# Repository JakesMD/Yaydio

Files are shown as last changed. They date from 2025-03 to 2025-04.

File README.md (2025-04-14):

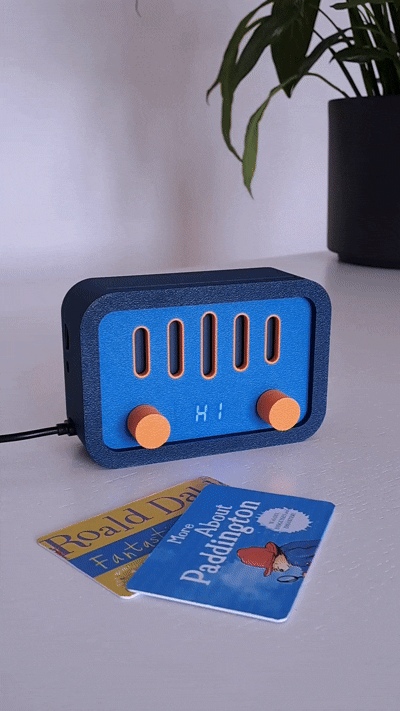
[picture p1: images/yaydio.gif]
Yaydio!


# Yaydio! 📻
**No more scratched CDs!**

**Yaydio!** is a portable music player designed for kids, ditching the hassle of CDs in favor of easy-to-use keycards.

## ✨ Features
- **Keycard playback:** Insert a keycard to instantly play an album.
- **Simple controls:** Play/pause, next/previous track, volume up/down.
- **Audio options:** Built-in speaker or connect headphones via the 3.5mm jack.
- **High capacity:**
    - Up to 999 songs per album
    - Up to 9999 albums
    - Up to 65535 songs in total
    - Supports micro SD cards up to 32GB.
- **MP3 compatibility:** Plays all your favorite MP3 files.
- **Affordable & accessible:** Works with cost-effective MF S50 RFID keycards.

## 🕹️ Usage

### Play / pause
Inserting a keycard into the **Yaydio!** will automatically start the playback.

Press either knob to pause or resume the playback.

Remove the keycard to stop the playback.

### Volume control
Turn the left knob to increase or decrease the volume.

### Next / previous track
Turn the right knob to skip to the next or previous track.

### Setup
1. Format the SD card to FAT16 or FAT32 and name it `YAYDIO`.
2. Copy the `README.txt` file onto the SD card.
3. Windows only: Download [DriveSort](https://www.anerty.net/software/file/DriveSort/?lang=en) and copy `DriveSort.exe` onto the SD card.
4. macOS only: Download [FatDriveSorter](https://fat-drive-sorter.netlify.app) and copy `FatDriveSorter.app` onto the SD card.

### Add albums to the SD card
1.  Create a new folder named `0001`, where "1" represents the next album number.
2.  Copy the album's songs into the folder you created.
3.  Rename the first song of the album to `001.mp3`.
4.  Repeat steps 1-3 for each album.
5.  Windows only: Use `DriveSort` to sort the files alphabetically in the SD card's table.
    -   Sort by `long name` and `ascending`.
    -   Remember to press the save button.
    -   You may need to sort every new folder individually and press save after each one.
6.  macOS only: Use `FatDriveSorter` to sort the files alphabetically in the SD card's table.
    -   Next to `Order:` select `Directories first`.
    -   Tick the box next to `Case-sensitive:`.

### Assign an album to a keycard

1. Insert the keycard into the **Yaydio!**.
2. Press the left and right knobs simultaneously.
3. Turn the right knob to select the album number.
4. Press the right knob to write the album number to the keycard.

## 🔨 Make your own

### 🧱 Parts
For a list of parts see [this issue](https://github.com/JakesMD/Yaydio/issues/1).

### 🧵 Wiring

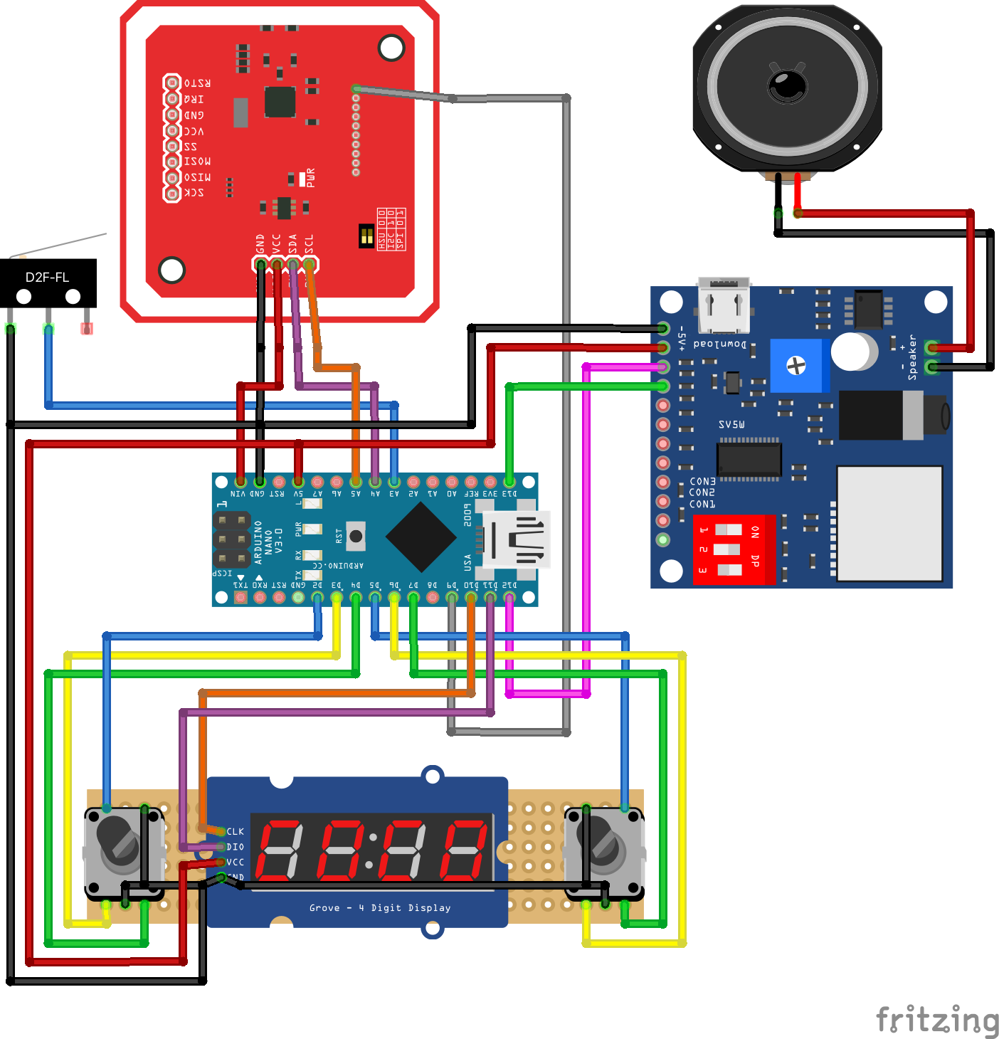
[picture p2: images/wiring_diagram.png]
Wiring Diagram


| Left Rotary Encoder | Arduino Nano |
| --- | --- |
| SW | D2 |
| SW GND | GND |
| DT | D3 |
| CLK | D4 |
| GND | GND |

| Right Rotary Encoder | Arduino Nano |
| --- | --- |
| SW | D5 |
| SW GND | GND |
| DT | D6 |
| CLK | D7 |
| GND | GND |

| 4-Digit 7-Segment 0.36 Inch TM1637 | Arduino Nano |
| --- | --- |
| CLK | D10 |
| DIO | D11 |
| GND | GND |
| 5V | 5V |

| Card Switch | Arduino Nano |
| --- | --- |
| NO | A3 |
| COM | GND |

| PN532 NFC Module V3 | Arduino Nano |
| --- | --- |
| GND | GND |
| VCC | VIN (NOT 5V) |
| SDA | A4 |
| SCL | A5 |
| RSTPDN | D9 |
| Switches: ON, OFF (I2C mode) |

Note: In the images below you'll see that I also connected the IRQ pin to the Arduino. This is not required.

| DY-SV5W Voice Module  | Arduino Nano |
| --- | --- |
| - | GND |
| + | 5V |
| TXD | D12 |
| RXD | D13 |
| Switches: OFF, OFF, ON (UART mode) |

| DY-SV5W Voice Module  | Speaker |
| --- | --- |
| Speaker + | + |
| Speaker - | - |

### 🏗️ Assembly

[yaydio.step](yaydio.step) contains the models of the 3D-printed parts.

**Printer:** Bambu Lab A1 with AMS

**Nozzle:** 0.4mm

**Preset:** `0.20mm Standard @BBL A1` with supports enabled

**Filaments:**
- Bambu Lab PLA Matte Mandarin Orange (11300)
- Bambu Lab PLA Matte Marine Blue (11600)
- Bambu Lab PLA Matte Dark Blue (11602)

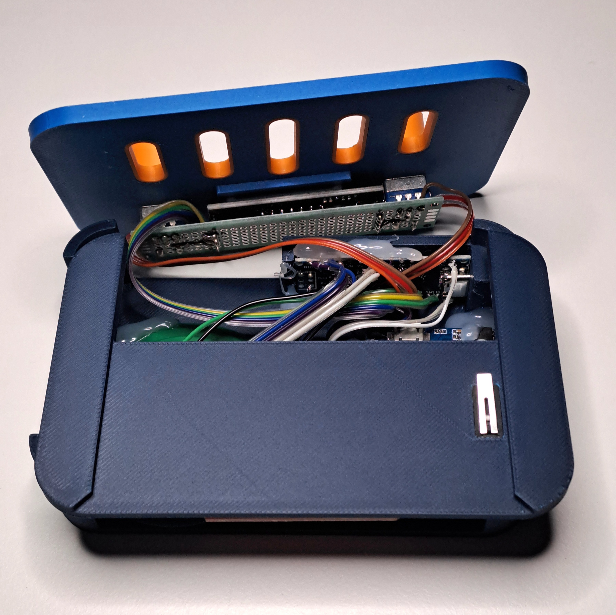
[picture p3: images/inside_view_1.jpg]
Inside view 1

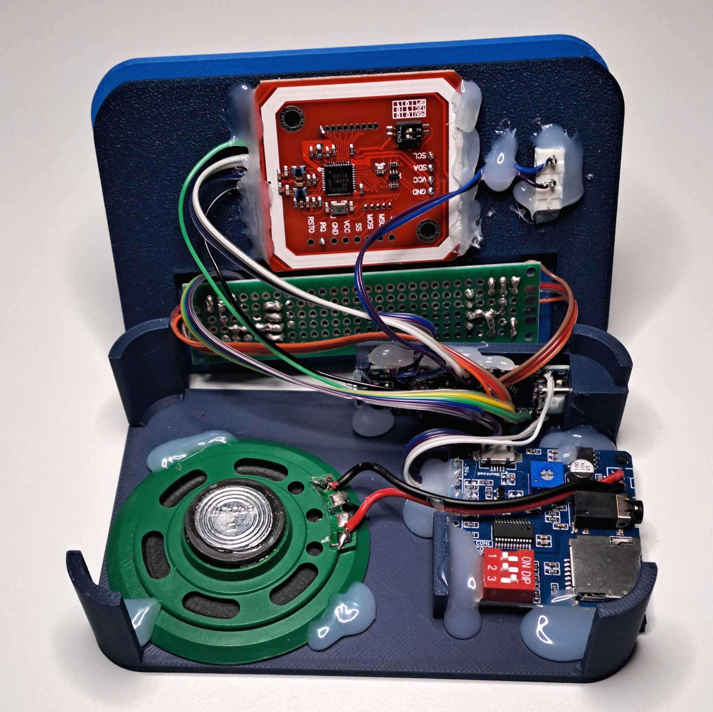
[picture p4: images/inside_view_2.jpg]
Inside view 2


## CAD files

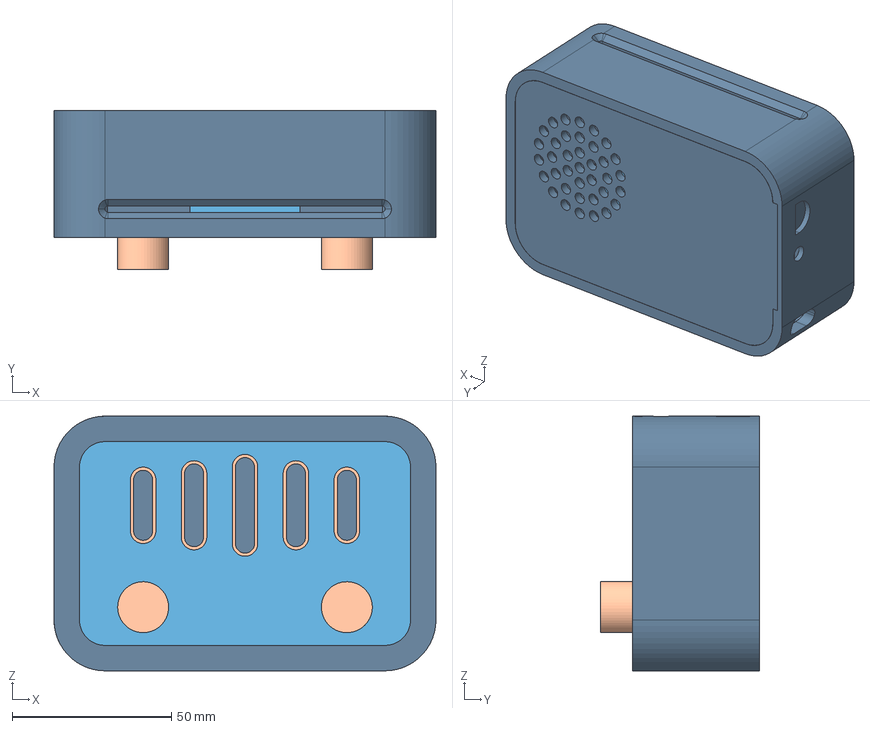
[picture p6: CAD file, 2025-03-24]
yaydio.step
120.0 x 50.0 x 80.0 mm
Front Plate
Knob x 2
Back Plate
NFC Plate

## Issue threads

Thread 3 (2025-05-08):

Suggestion: Allow reading NFC cards across Yaydio devices even if UID differs

iliesaya, 2025-05-08:
Hi,

  I built two Yaydio devices and ran into an interoperability issue when using NFC cards across devices.

  ### 🔧 What happens:

  If I write an NFC card with one Yaydio device (e.g., writing block 4 with an album number and a custom UID), the second Yaydio device **fails to read** it, even though the block structure and keys are valid. The NFC read operation returns `FAIL`.

  After debugging, I realized this happens because the card’s UID is different from what the reading Yaydio device expects or assumes internally.

  ### 🧪 Repro case:

  - Device A writes album 0002 to a card with UID: `1E 0C 58 3E`
  - Device B writes album 0002 to a card with UID: `36 69 63 3E`
  - Each device can read its own card correctly
  - The other device fails to read the card written by the other one

  This means that Yaydio currently **ties the album reading logic to the UID**, which is problematic when using UID-writable “magic” MIFARE Classic cards or cloning workflows (e.g., with Flipper Zero).

  ### 💡 Suggestion:

  Please consider modifying the NFC handling logic in Yaydio so that reading a card is based only on successful authentication (key match) and block 4 content — and **not dependent on UID value**.

  That way, the same NFC card can be used across all Yaydio devices regardless of UID.

  I’m attaching two `.nfc` files (named `0002.nfc`) from two different Yaydio devices, both pointing to the same album but with different UIDs, to illustrate the problem.

  I don't currently have the time to create a pull request and validate changes, but I hope this report helps guide a fix.

  Thanks for the great project!

[two_yaydio_device_nfc_dump.zip](https://github.com/user-attachments/files/20103577/two_yaydio_device_nfc_dump.zip)

JakesMD, 2025-05-09:
Hi! Thanks for the feedback! I'll have to dig into the issue when I next get time.

Cool to hear that you've already made two of them!

JakesMD, 2025-05-09:
Is your "magic" keycard an ISO14443 or something else? I don't know whether it's even possible for the Yaydio to support anything else. Do you happen to have a standard ISO14443 you could test this with? I think you're currently the only person to own multiple Yaydios XD

iliesaya, 2025-05-11:
Yes, the card I'm using is a magic MIFARE Classic 1K (ISO14443A) card with a writable UID. It is fully ISO14443A-compatible, just with the added ability to reprogram Block 0 (UID) using tools like Flipper Zero or Arduino+PN532.

Here's the exact card I purchased and tested with:
🔗 https://www.aliexpress.com/item/1005006127590709.html?spm=a2g0o.order_list.order_list_main.125.2fd61802nkmXpS
(10-100 Pcs 13.56 MHz UID Rewritable Block 0 Changeable Smart NFC RFID Tag Chip Access Control Card for Copy 1K S50 MF1 M1)
To clarify:

The card works independently and correctly with both Yaydio devices.

The only reason a card written by one device fails to be read by the other is because of a UID mismatch, not a protocol or card type incompatibility.

The authentication key and data layout are the same — only the UID differs.

I believe decoupling UID from the album loading logic would make cards interchangeable between Yaydios.

I don’t currently have a standard (non-magic) MIFARE card on hand.

JakesMD, 2025-05-13:
I understand. Yes, the Yaydio uses the UID to authenticate the block 4. But why should the UID be different between PN532s? Seems weird.

Looking at block 0 I find this: `62 63 64 65 66 67 68 69` that should be `FF FF FF FF FF FF FF FF`. Note that the bytes are very similar and in fact represent `bcdefghi` in ASCII.

That looks like a hardware issue to me. There might be something wrong with your PN532.

JakesMD, 2025-05-13:
When you created the `.nfc` files, did you write the album to the card with each Yaydio, or did you write the album with one Yaydio and just read the card with the other?

What happens when you write to the card with one Yaydio and then print out the what the other Yaydio sees? I saw that in both `.nfc` files the album number is correct.

It's interesting that the 5th byte (the checksum, XOR over the UID) is correct in both cases. So somehow the PN532s are reading 2 different UIDs that happen to both be correct. Crazy!

JakesMD, 2025-05-13:
I reckon I've worked it out. Your Aliexpress link states:
> Unique Encrypted ID: Each card comes with a unique encrypted ID number that can be reprogrammed, ensuring high security and flexibility.

The UID of a standard MIFARE Classic card is **not encrypted** and **not reprogrammable**.

After a bit of research, you don't want "magic" cards. You just want standard ones with fixed UIDs.

Closed 2025-05-13.

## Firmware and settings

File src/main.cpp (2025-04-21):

#include <Arduino.h>
#include <TM1637Display.h>

#include "button.h"
#include "config.h"
#include "display.h"
#include "mp3_player.h"
#include "nfc.h"
#include "rotary_encoder.h"

YButton cardBtn(CARD_BTN_PIN);

YButton leftBtn(LEFT_BTN_PIN);
YButton rightBtn(RIGHT_BTN_PIN);

YRotaryEncoder leftRotaryEncoder(LEFT_CLK_PIN, LEFT_DT_PIN);
YRotaryEncoder rightRotaryEncoder(RIGHT_CLK_PIN, RIGHT_DT_PIN);

YDisplay display(DISP_CLK_PIN, DISP_DIO_PIN);

YNFC nfc(NFC_IRQ_PIN, NFC_RST_PIN);

YMP3Player mp3Player(MP3_RX_PIN, MP3_TX_PIN);

enum YMODE {
    NO_CARD_MODE,
    READ_CARD_MODE,
    WRITE_CARD_MODE,
    PLAYER_MODE,
    SET_ALBUM_MODE,
    NO_ALBUM_MODE,
    FAIL_MODE,
};

YMODE mode = NO_CARD_MODE;
bool hasModeChanged = true;
bool isNewModeComing = false;

bool wasRightBtnReleased = false;

unsigned long lastUpdate = 0;
unsigned long currentMillis = 0;

uint8_t selectedAlbum = 1;

void updateTrackScreen() {
    display.showTrack(mp3Player.currentTrack(), mp3Player.isPlaying());
    lastUpdate = currentMillis;
}

void changeMode(YMODE newMode) {
    mode = newMode;
    isNewModeComing = true;
}

bool tryInitializePeripherals(int attempts = 5) {
    for (int i = 0; i < attempts; ++i) {
        if (nfc.begin() && mp3Player.begin()) {
            return true;
        }
        Serial.println("delay 500ms");
        delay(500);
    }
    return false;
}

void setup() {
    Serial.begin(115200);
    Serial.println("Hi!");

    if (!tryInitializePeripherals()) {
        display.showFail();
        while (true);
    }
}

void loop() {
    cardBtn.loop();
    leftBtn.loop();
    rightBtn.loop();
    leftRotaryEncoder.loop();
    rightRotaryEncoder.loop();

    currentMillis = millis();

    switch (mode) {
        case NO_CARD_MODE:
            if (hasModeChanged) {
                mp3Player.stop();
                display.showHi();
            }
            if (cardBtn.isPressed()) changeMode(READ_CARD_MODE);
            break;

        case READ_CARD_MODE:
            if (hasModeChanged) {
                display.showLoading();
                mp3Player.stop();
            }
            switch (nfc.read()) {
                case NO_CARD:
                    changeMode(NO_CARD_MODE);
                    break;
                case SUCCESS:
                    selectedAlbum = nfc.album();
                    changeMode(selectedAlbum == 0 ? NO_ALBUM_MODE : PLAYER_MODE);
                    break;
                case FAIL:
                    changeMode(FAIL_MODE);
                    break;
            }
            break;

        case WRITE_CARD_MODE:
            if (hasModeChanged) display.showLoading();
            switch (nfc.setAlbum(selectedAlbum)) {
                case NO_CARD:
                    changeMode(NO_CARD_MODE);
                    break;
                case SUCCESS:
                    if (selectedAlbum == 0) {
                        changeMode(NO_ALBUM_MODE);
                    } else {
                        changeMode(PLAYER_MODE);
                    }
                    break;
                case FAIL:
                    changeMode(FAIL_MODE);
                    break;
            }
            break;

        case PLAYER_MODE:
            if (hasModeChanged) {
                mp3Player.playAlbum(selectedAlbum);
                updateTrackScreen();
            }

            if (cardBtn.isReleased()) {
                changeMode(NO_CARD_MODE);
                break;
            }

            if (leftBtn.justReleased() || rightBtn.justReleased()) {
                mp3Player.togglePlayback();
                updateTrackScreen();
            }

            if (leftBtn.isPressed() && rightBtn.isPressed()) {
                changeMode(SET_ALBUM_MODE);
                break;
            }

            if (leftRotaryEncoder.justTurnedCW()) {
                mp3Player.increaseVolume();
            } else if (leftRotaryEncoder.justTurnedCCW()) {
                mp3Player.decreaseVolume();
            }

            if (rightRotaryEncoder.justTurnedCW()) {
                mp3Player.next();
                updateTrackScreen();
            } else if (rightRotaryEncoder.justTurnedCCW()) {
                mp3Player.previous();
                updateTrackScreen();
            }

            if (currentMillis - lastUpdate > 1000) updateTrackScreen();

            break;

        case SET_ALBUM_MODE:
            if (hasModeChanged) {
                mp3Player.stop();
                wasRightBtnReleased = false;
                if (selectedAlbum == 0) selectedAlbum = 1;
                display.showAlbum(selectedAlbum);
            }

            if (cardBtn.isReleased()) {
                changeMode(NO_CARD_MODE);
                break;
            }

            if (rightBtn.justReleased()) {
                if (wasRightBtnReleased) {
                    changeMode(WRITE_CARD_MODE);
                } else {
                    wasRightBtnReleased = true;
                }

            } else if (selectedAlbum < 9999 && rightRotaryEncoder.justTurnedCW()) {
                selectedAlbum++;
                display.showAlbum(selectedAlbum);
            } else if (selectedAlbum > 0 && rightRotaryEncoder.justTurnedCCW()) {
                selectedAlbum--;
                display.showAlbum(selectedAlbum);
            }

            break;

        case NO_ALBUM_MODE:
            if (hasModeChanged) {
                mp3Player.stop();
                display.showBlank();
            }
            if (cardBtn.isReleased()) {
                changeMode(NO_CARD_MODE);
                break;
            }
            if (leftBtn.isPressed() && rightBtn.isPressed()) {
                changeMode(SET_ALBUM_MODE);
                break;
            }
            if (rightBtn.justReleased()) {
                changeMode(READ_CARD_MODE);
                break;
            }
            break;

        case FAIL_MODE:
            if (hasModeChanged) {
                lastUpdate = currentMillis;
                display.showFail();
                mp3Player.stop();
            } else if (currentMillis - lastUpdate > 2000) {
                changeMode(NO_CARD_MODE);
            }
            break;
    }

    if (isNewModeComing) {
        hasModeChanged = true;
        isNewModeComing = false;
    } else {
        hasModeChanged = false;
    }
}

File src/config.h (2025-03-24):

// Card contact switch
#define CARD_BTN_PIN A3

// Display
#define DISP_CLK_PIN 10
#define DISP_DIO_PIN 11

// Left button
#define LEFT_BTN_PIN 2

// Right button
#define RIGHT_BTN_PIN 5

// Left rotary encoder
#define LEFT_CLK_PIN 4
#define LEFT_DT_PIN 3

// Right rotary encoder
#define RIGHT_CLK_PIN 7
#define RIGHT_DT_PIN 6

// PN532 (NFC)
#define NFC_IRQ_PIN 8
#define NFC_RST_PIN 9

// DY-SV5W (MP3 Player)
#define MP3_RX_PIN 12
#define MP3_TX_PIN 13

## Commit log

2025-03-17 🎉 Initial commit
2025-03-20 ✨ It works!
2025-03-23 ✨ Add card switch
2025-03-24 ⚡️ Remove delay
2025-03-24 🐛 Fix wrong pin
    [config.h]
2025-03-24 ✨ Add ability to wipe a card
2025-03-24 🔥 Clean up
2025-03-24 📝 Add documentation
2025-03-24 ✏️ Fix typo
2025-03-24 ✨ Add 3D model
    [yaydio.step]
2025-03-24 🔥 Delete DS_Store
2025-03-24 📝 Add wiring
2025-03-24 ✨ Add wiring diagram
    [wiring_diagram.fzz]
2025-03-24 ⬆️ Saved with imported parts
    [schematic.fzz]
2025-03-24 ✏️ Rename Fritzing file
    [schematic.fzz, wiring_diagram.fzz]
2025-03-24 ⚖️ Add license
2025-03-24 🎨 Improve wiring
    [wiring_diagram.fzz]
2025-03-24 📝 Add assembly docs
2025-03-24 📝 Improve documentation
2025-03-24 ✏️ Fix typos
2025-03-25 ✨ Add photo
2025-03-30 📝 Add README.txt for the SD card
2025-03-31 ✨ Make right button play / pause too
2025-03-31 📝 Add parts list
2025-04-14 📝 Add GIF to README
2025-04-20 The NFC module (PN532) or MP3 player (DY-SV5W) may not be fully powered up yet.
